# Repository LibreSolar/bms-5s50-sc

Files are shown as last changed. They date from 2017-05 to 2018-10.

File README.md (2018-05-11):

# BMS 5s (12 V)

Battery management system for up to 5 Li-ion cells based on bq76920 IC from Texas Instruments

## Boards

The Libre Solar BMS is divided into two different boards, connected via a flat cable and integrated into one housing.

### Control board (BMS 5s)

[Schematic (PDF)](power-pcb/Switch-N-Sense.pdf)

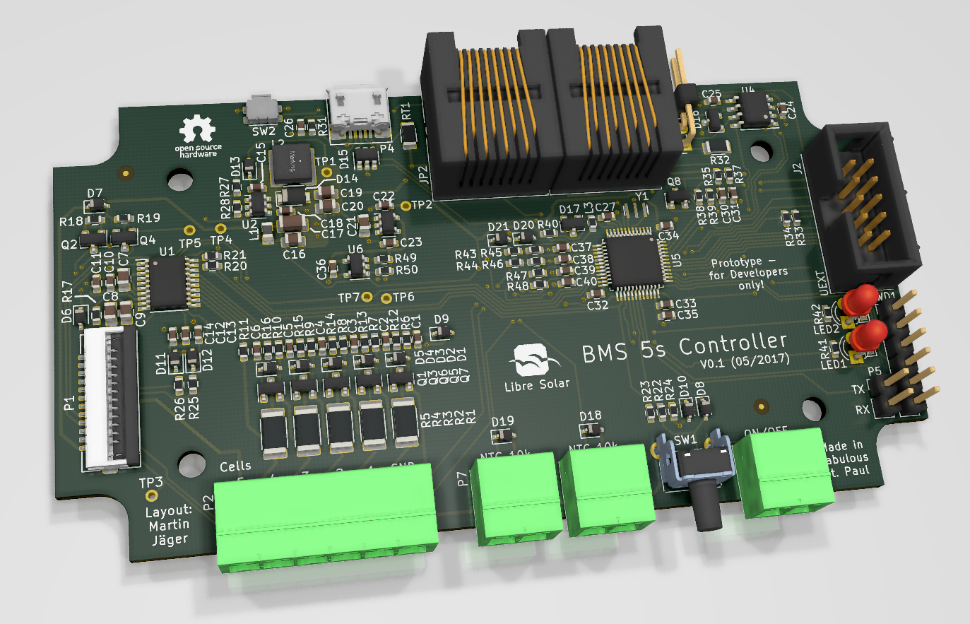
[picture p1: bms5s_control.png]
Libre Solar BMS 5s control board


### Power board (Switch-N-Sense)

[Schematic (PDF)](control-pcb/BMS-5s.pdf)

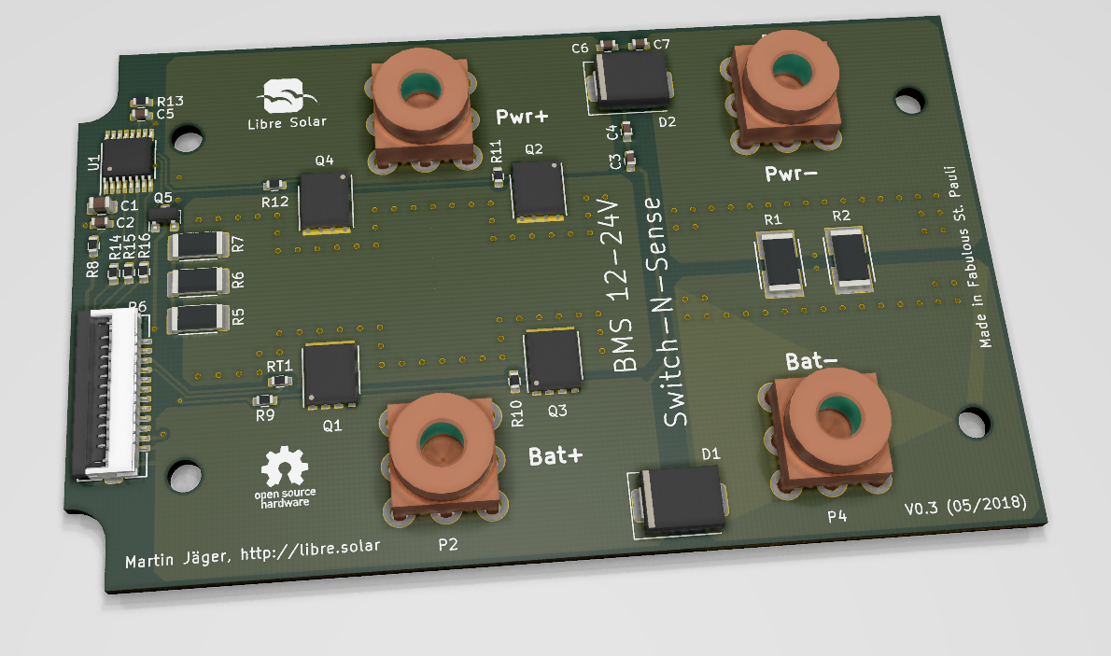
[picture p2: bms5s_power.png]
Libre Solar BMS 5s power board


## Features

- 3 to 5 Li-ion cells (e.g. LiFePO4)
- 50 A maximum current
- Balancing current approx. 150 mA
- STM32F072 ARM Cortex M0 microcontroller
- Built-in CAN communication interface and UEXT extension connector

## Housing

The BMS should fit into a Hammond Mfg 1591XXBFL housing as shown in below picture. The picture shows the BMS controller PCB with the Switch-N-Sense power PCB stacked on top of it:

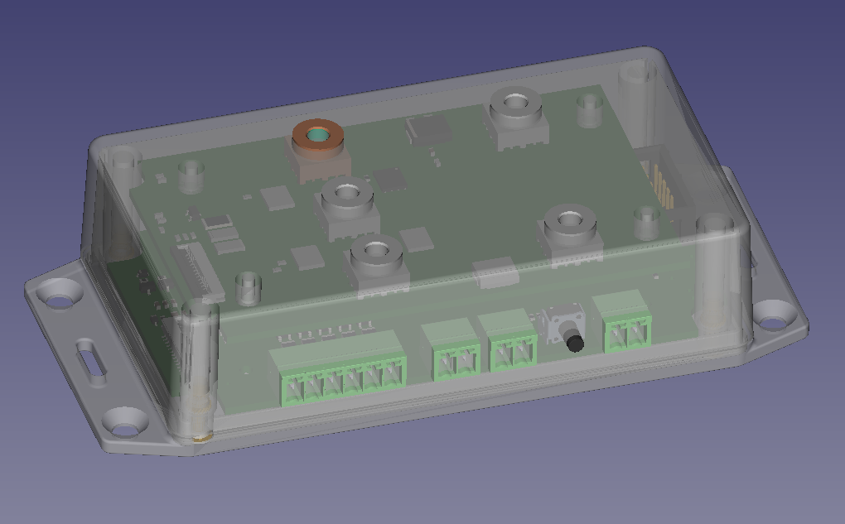
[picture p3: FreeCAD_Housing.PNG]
Libre Solar BMS 5s including housing


## History

- There is [another version of the BMS](https://github.com/LibreSolar/BMS48V)  supporting more cells and developed in Eagle CAD. This one is the first of the new BMS generation developed in KiCad. An updated version of the versions with higher number of cells might come soon.

## Important Notice

The PCBs have not been tested regarding EMC and other regulations. If you reproduce the boards, you use them at your own risk and responsibility.

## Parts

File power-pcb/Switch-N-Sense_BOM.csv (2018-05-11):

Component | Description | Part | References | Value | Footprint | Quantity Per PCB | Datasheet | PartNumber | Manufacturer | Remarks
1 | Unpolarized capacitor | C | C3 C4 C6 C7 | 100n | C_0603_1608 | 4 |  | CC0603KRX7R9BB104 | Yageo
2 | Unpolarized capacitor | C | C2 C5 | 10n | C_0603_1608 | 2 |  | CC0603KRX7R9BB103 | Yageo
3 | Unpolarized capacitor | C | C1 | 1u | C_0805_2012 | 1 |  | CC0603KRX7R8BB105 | Yageo
4 | Diode Schottky | D_Schottky | D1 D2 | SMCJ24A | D_SMC | 2 |  | SMCJ24A | Bourns
5 |  | LibreSolar_Logo | LOGO1 | LIBRE_SOLAR | LIBRESOLAR_LOGO | 1
6 | small Open Hardware Logo | Logo_Open_Hardware_Small | LOGO2 | OPEN_HARDWARE_1 | OSHW-Logo_5.7x6mm_SilkScreen | 1
7 | Generic connector, single row, 01x01, script generated (kicad-library-utils/schlib/autogen/connector/) | Conn_01x01 | P2 P3 P4 P5 | CONN_01X01 | Wuerth_WP-THRBU | 4 |  | 74650195 | Wuerth
8 |  | Conn_Switch-N-Sense_Inverted | P6 | Conn_Switch-N-Sense | Wuerth_WR-FPC_686112148922 | 1 |  | 686112148922 | Wuerth
9 | Transistor N-MOSFET (general) | Q_NMOS | Q1 Q2 Q3 Q4 | BSC014N04LS | 5X6_MOSFET | 4 |  | BSC014N04LS | Infineon
10 | Transistor P-MOSFET with substrate diode (general) | Q_PMOS_GSD | Q5 | ZXMP6A13F | SOT-23 | 1 |  | ZXMP6A13FTA | Diodes Incorporated | -60V
11 | Resistor | R | R8 R13 | 100 | R_0603_1608 | 2 |  | RC0603FR-07100RL | Yageo
12 | Resistor | R | R10 R11 | 1M | R_0603_1608 | 2 |  | RC0603FR-071ML | Yageo
13 | Resistor | R | R14 R15 R16 | 1k | R_0603_1608 | 3 |  | RC0603FR-071KL | Yageo
14 | Resistor | R | R1 R2 | 2m | R_Bourns_CRE2512 | 2 |  | CRE2512-FZ-R002E-3 | Bourns
15 | Resistor | R | R5 R6 R7 | 330 | R_2010_5025 | 3 |  | RC2010JK-07330RL | Yageo
16 | Resistor | R | R9 R12 | 4.7 | R_0603_1608 | 2 |  | RC0603FR-074R7L | Yageo
17 |  | R_NTC | RT1 | 10k | R_0603_1608 | 1 |  | NTCG163JF103FT1S | TDK
18 |  | BQ76200 | U1 | BQ76200 | TSSOP-16_4.4x5mm_P0.65mm | 1 |  | BQ76200PWR | Texas Instruments
Component Groups: | 18
Component Count: | 37
Fitted Components: | 37
Number of PCBs: | 1
Total components: | 37
Schematic Version: | 0.2
Schematic Date:
BoM Date: | 11/05/2018 13:48:19
Schematic Source: | D:\LibreSolar\2_Development\04_Hardware\BMS-5s\power-pcb\Switch-N-Sense.sch
KiCad Version: | Eeschema (5.0.0-rc2-dev-444-g2974a2c10)

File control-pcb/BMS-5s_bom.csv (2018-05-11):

Component | Description | Part | References | Value | Footprint | Quantity Per PCB | Datasheet | PartNumber | Manufacturer | Remarks | Alternative | Tolerance
1 | Unpolarized capacitor | C | C1 C2 C3 C4 C5 C6 C11 C12 C13 C14 C15 C18 C24 C25 C26 C27 C31 C32 C33 C34 C36 C37 C38 C39 C40 | 100n | C_0603_1608 | 25 |  | GRM188R71H104KA93D | Murata
2 | Unpolarized capacitor | C | C23 | 100p | C_0603_1608 | 1 |  | GRM1885C2A101JA01D | Murata
3 | Unpolarized capacitor | C | C8 C19 C20 | 10u | C_0805_2012 | 3 |  | GRM21BR61E106KA73L | Murata
4 | Unpolarized capacitor | C | C7 C9 C16 C21 | 1u | C_0603_1608 | 4 |  | GRM188R61H105KAALD | Murata | X5R
5 | Unpolarized capacitor | C | C10 C22 C30 C35 | 4.7u | C_0603_1608 | 4 |  | GRM188R61A475KE15D | Murata | 10V
6 | Unpolarized capacitor | C | C17 | 4.7u | C_1206_3216 | 1 |  | GRM31CR71H475MA12L | Murata
7 | Diode | D | D6 D8 D13 | 1N4148W-7-F | D_SOD-323 | 3 |  | 1N4148W-7-F | Diodes Inc.
8 | Diode zener | D_Zener | D9 D10 D11 D12 D18 D19 D20 D21 | 3.3V | D_SOD-323 | 8 |  | MM3Z3V3T1G | ON Semiconductor
9 | Diode zener | D_Zener | D1 D2 D3 D4 D5 D7 | 5.6V | D_SOD-323 | 6 |  | MM3Z5V6T1G | ON Semiconductor |  | BZX384-C5V6
10 |  | LM4040 | D17 | LM4040CYM3-2.5 | SOT-23 | 1 |  | LM4040DYM3-2.5-TR | Microchip
11 |  | NUP2105L | D16 | NUP2105L | SOT-23 | 1 |  | NUP2105LT1G | ON Semiconductor
12 | Diode Schottky | D_Schottky | D14 | SS16FP | D_PowerDI-123 | 1 |  | SS16FP | Diodes Inc. |  | DFLS160-7
13 |  | USBLC6-2SC6 | D15 | USBLC6-2SC6 | SOT-23-6 | 1 |  | USBLC6-2SC6 | STMicroelectronics |  | WE-TVS 82400102
14 |  | UEXT | J2 | UEXT | Box_Header_2x05x2.54mm_Straight | 1 |  | 61201021621 | Würth
15 | Jumper normally close | Jumper_NC_Small | JP1 | Jumper_NC_Small | Pin_Header_Angled_2x01_Pitch2.54mm | 1
16 |  | RJ45_NS | JP2 JP3 | RJ45_NS | RJ45_8P8C | 2 |  | 54602-908LF | Amphenol FCI
17 | Inductor | L | L2 | 22uH | L_WE-TPC-4818 | 1 |  | SRR4028-220Y | Bourns |  | WE-TPC-4818 744042220
18 | Inductor | L | L1 | 4.7uH | L_0805 | 1 |  | LQM21PN4R7NGRD | Murata
19 | Inductor | L | L3 | L | R_0603_1608 | 1 |  | BLM18AG601SN1D | Murata
20 |  | LED | LED1 LED2 | LED | LED_D3.0mm | 2
21 | Libre Solar Logo | LIBRE_SOLAR | LOGO2 | LIBRE_SOLAR | LIBRESOLAR_LOGO | 1
22 | Open Hardware Logo | OPEN_HARDWARE_1 | LOGO1 | OPEN_HARDWARE_1 | OSHW-Logo_5.7x6mm_SilkScreen | 1
23 | Connector, single row, 01x02, pin header | CONN_01X02 | P5 | CONN_01X02 | Pin_Header_Straight_1x02_Pitch2.54mm | 1
24 | Connector, single row, 01x02, pin header | CONN_01X02 | P6 P7 | CONN_01X02 | Phoenix_Contact_PTSM_0.5_2-HH-2,5-THR-R16 | 2
25 | Connector, single row, 01x06, pin header | CONN_01X06 | P2 | CONN_01X06 | Phoenix_Contact_MC_1,5_6-G-3,81 | 1 |  | 1803316 | Phoenix Contact | MC 1,5/ 6-G-3,81
26 |  | Conn_Switch-N-Sense | P1 | Conn_Switch-N-Sense | Wuerth_WR-FPC_687112149022 | 1 |  | 687112149022 | Würth
27 | Connector, single row, 01x02, pin header | CONN_01X02 | P3 | ON/OFF | Phoenix_Contact_PTSM_0.5_2-HH-2,5-THR-R16 | 1 |  |  | Phoenix Contact
28 |  | USB_OTG | P4 | USB_Micro-B | USB_Micro-B_10103594-0001LF | 1 |  | 10103594-0001LF | FCI
29 | Transistor N-MOSFETwith substrate diode (general) | Q_NMOS_GSD | Q4 Q8 Q9 | 2N7002 | SOT-23 | 3 |  | 2N7002,215 | Nexperia
30 | Transistor N-MOSFETwith substrate diode (general) | Q_NMOS_GSD | Q2 | BSS84 | SOT-23 | 1 |  | BSS84 | Fairchild Semiconductor
31 | Transistor N-MOSFETwith substrate diode (general) | Q_NMOS_GSD | Q1 Q3 Q5 Q6 Q7 | DMN2004K | SOT-23 | 5 |  | DMN2004K-7 | Diodes Incorporated
32 | Resistor | R | R17 | 100 | R_0603_1608 | 1 |  | RC0603FR-07100RL | Yageo
33 | Resistor | R | R18 R19 R24 R31 R43 R44 | 100k | R_0603_1608 | 6 |  | RC0603FR-07100KL | Yageo
34 | Resistor | R | R12 R13 R14 R15 R16 R22 R28 R40 R45 R46 R47 R48 | 10k | R_0603_1608 | 12 |  | RC0603FR-0710KL | Yageo
35 | Resistor | R | R32 | 120 | R_1206_3216 | 1 |  | RC1206FR-07120RL | Yageo
36 | Resistor | R | R21 R35 R37 | 1M | R_0603_1608 | 3 |  | RC0603FR-071ML | Yageo
37 | Resistor | R | R6 R7 R8 R9 R10 R11 R20 R25 R26 | 1k | R_0603_1608 | 9 |  | RC0603FR-071KL | Yageo
38 | Resistor | R | R33 R34 R38 R49 R50 | 2.2k | R_0603_1608 | 5 |  | RC0603FR-072K2L | Yageo
39 | Resistor | R | R1 R2 R3 R4 R5 | 33 | R_2010_5025 | 5 |  | RC2010JK-0733RL | Yageo
40 | Resistor | R | R41 R42 | 330 | R_0603_1608 | 2 |  | RC0603FR-07330RL | Yageo
41 | Resistor | R | R23 | 5.6K | R_0603_1608 | 1 |  | RC0603FR-075K6L | Yageo
42 | Resistor | R | R27 R39 | 52.3k | R_0603_1608 | 2 |  | RC0603FR-0752K3L | Yageo
43 |  | R_PTC | RT1 | 200mA | R_0805_2012 | 1 |  | 0805L020 | Littelfuse
44 | Button | SW_PUSH | SW1 | SW_PUSH | SW_Tactile_SKHH_Angled | 1 |  | 431256083716 | Würth
45 | Button | SW_PUSH | SW2 | SW_PUSH | SW_SPST_EVQP7A | 1 |  | 434121050816 | Würth
46 |  | ST_Nucleo_SWD | SWD1 | ST_Nucleo_SWD | Pin_Header_Straight_1x05_Pitch2.54mm | 1
47 | Microchip 24AA01 1K I2C EEPROM | 24AA01 | U6 | 24AA01 | SOT-23-5 | 1 |  | 24AA01 | Microchip
48 | 300mA low dropout linear regulator, shutdown pin, 1.5V fixed positive output, SOT-23-5 package | AP2210-3.3 | U3 | AP2210-3.3 | SOT-23-5 | 1 | http://www.diodes.com/_files/datasheets/AP131.pdf | AP2210K-3.3TRG1 | Diodes Inc. |  | MIC5225
49 |  | BQ76920 | U1 | BQ76920 | TSSOP-20_4.4x6.5mm_Pitch0.65mm | 1 |  | BQ7692003PWR | Texas Instruments
50 | High-Voltage Input Integrated Switch Step-Down Regulator, 50V, 500mA | MCP16331-CH | U2 | MCP16331-CH | SOT-23-6 | 1 | http://ww1.microchip.com/downloads/en/DeviceDoc/20005308C.pdf | MCP16331T-E/CH | Microchip
51 |  | STM32F072CB | U5 | STM32F072CB | LQFP-48_7x7mm_Pitch0.5mm | 1 |  | STM32F072CBT6 | STMicroelectronics
52 | TJA1042T/3, High-Speed CAN Transceiver, separate VIO, standby mode, SOIC-8 | TJA1042T/3 | U4 | TJA1042T/3 | SOIC-8_3.9x4.9mm_Pitch1.27mm | 1 | http://www.nxp.com/documents/data_sheet/TJA1042.pdf | TJA1042T/3/1J | NXP
53 | Two pin crystal | Resonator | Y1 | 8kHz | Resonator_Murata_CSTCE | 1 |  | CSTCE8M00G15C99-R0 | Murata |  |  | 0.1%
Component Groups: | 53
Component Count: | 144
Fitted Components: | 144
Number of PCBs: | 1
Total components: | 144
Schematic Version: | 0.1b
Schematic Date: | 3 dec 2016
BoM Date: | 22/05/2017 16:05:45
Schematic Source: | D:\LibreSolar\2_Development\04_Hardware\BMS-5s\BMS-5s.sch
KiCad Version: | Eeschema (2017-05-10 revision 747583606)-makepkg

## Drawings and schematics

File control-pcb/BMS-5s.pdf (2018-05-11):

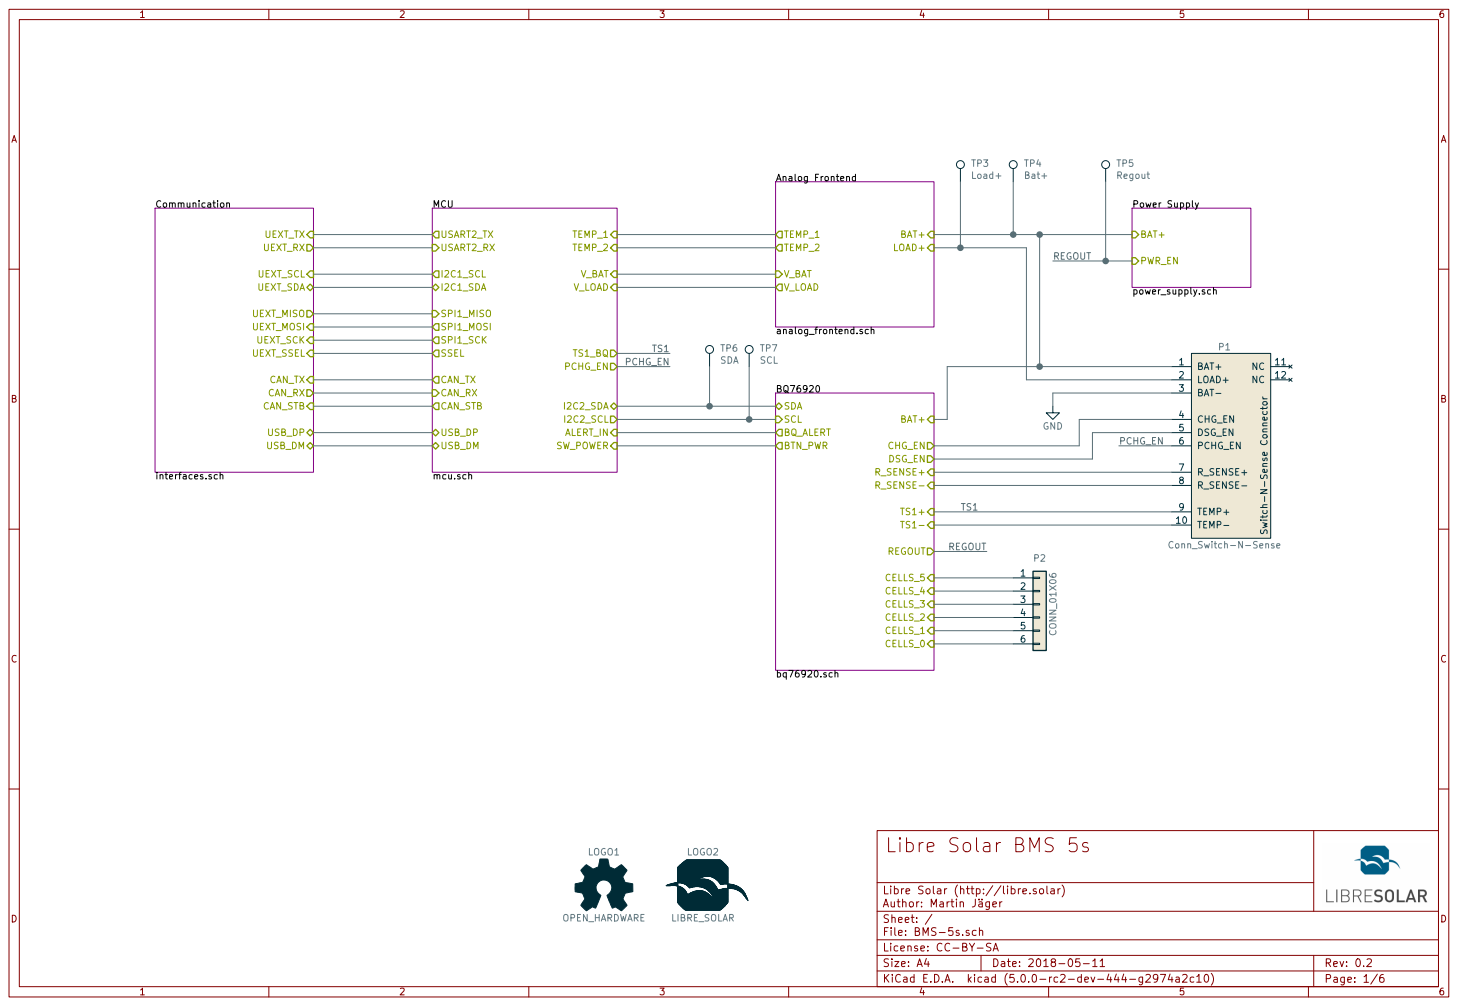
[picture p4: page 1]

File: BMS-5s.sch Sheet: / Libre Solar (http://libre.solar) License: CC-BY-SA
Author: Martin Jäger

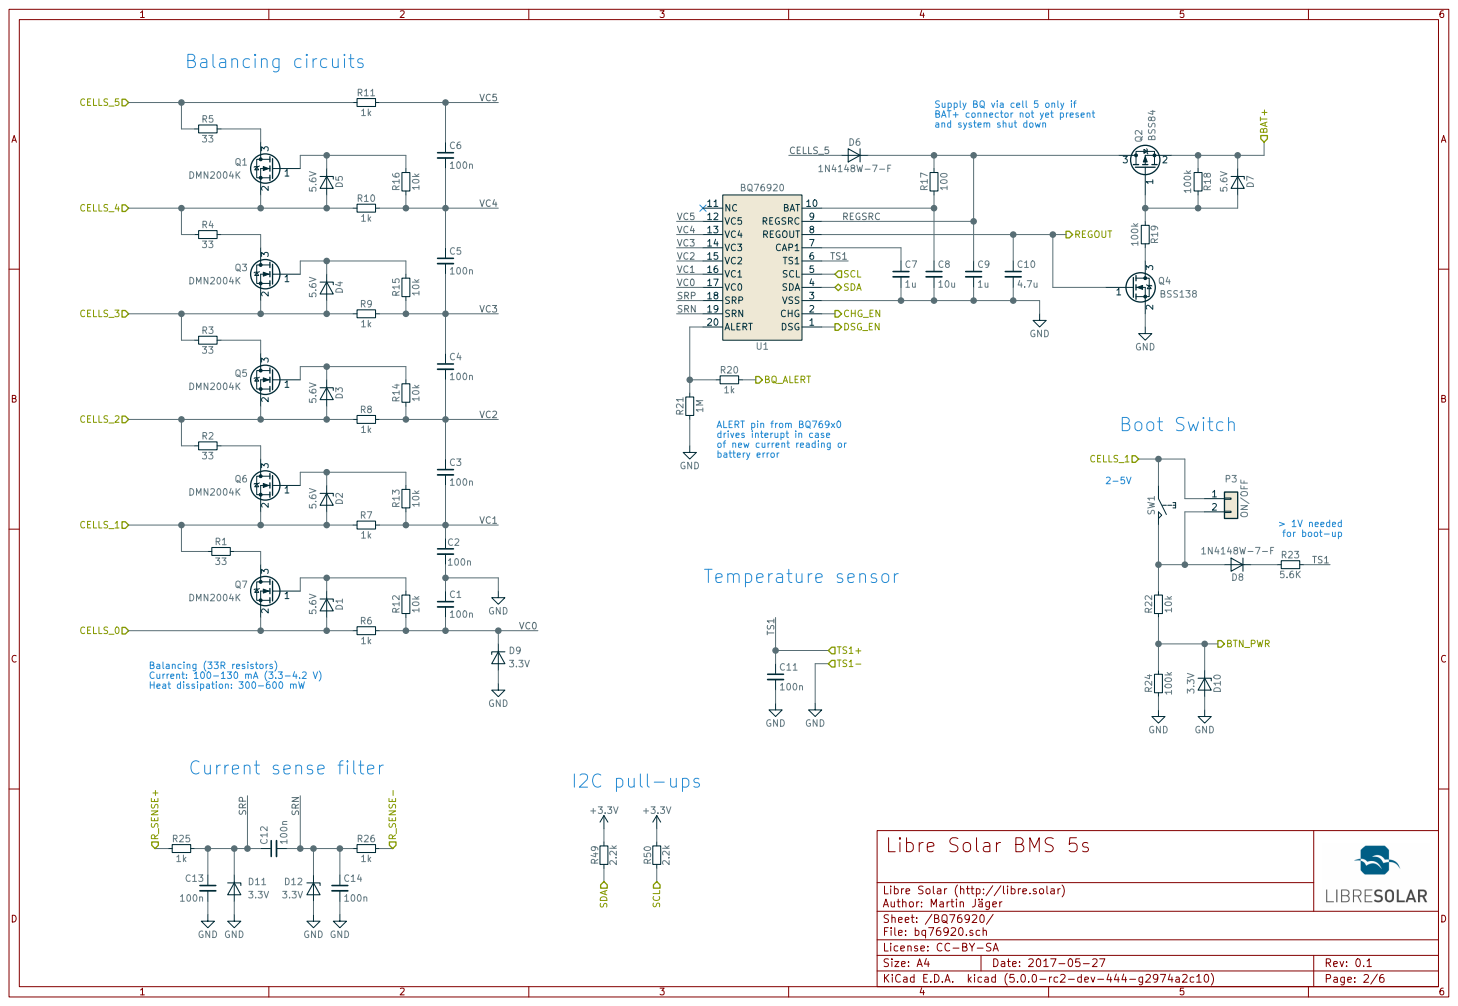
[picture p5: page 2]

REGOUT Supply BQ via cell 5 only if
BAT+ connector not yet present

2 3 Q7 DMN2004K GND GND GND GND GND GND

ALERT pin from BQ769x0
drives interupt in case
of new current reading or

Libre Solar (http://libre.solar) License: CC-BY-SA

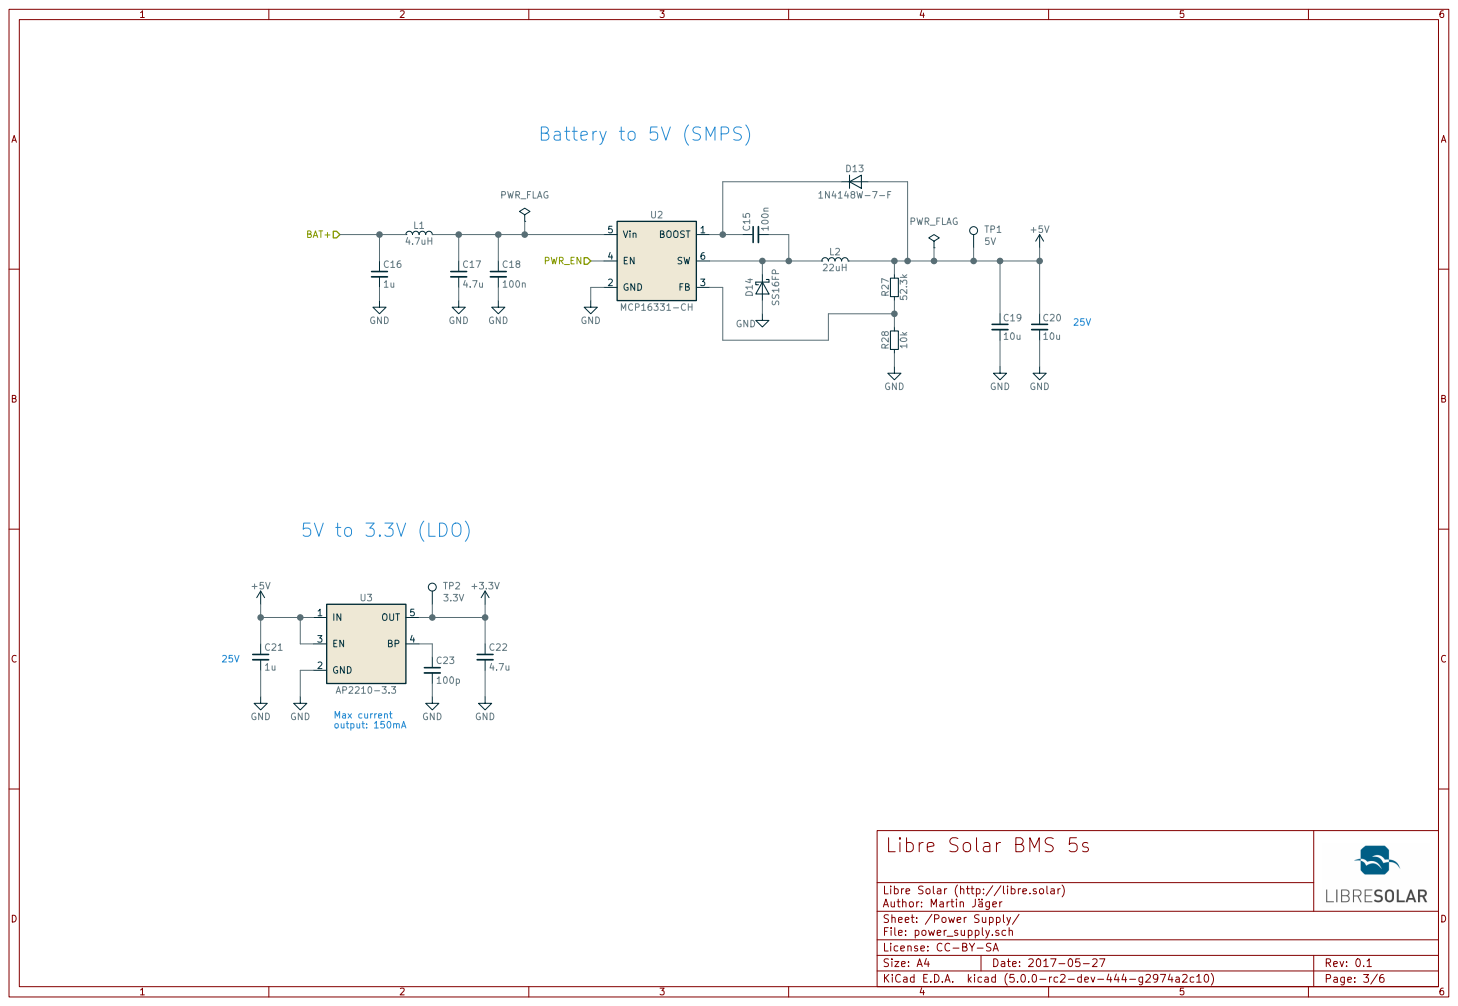
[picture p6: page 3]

Libre Solar (http://libre.solar) License: CC-BY-SA

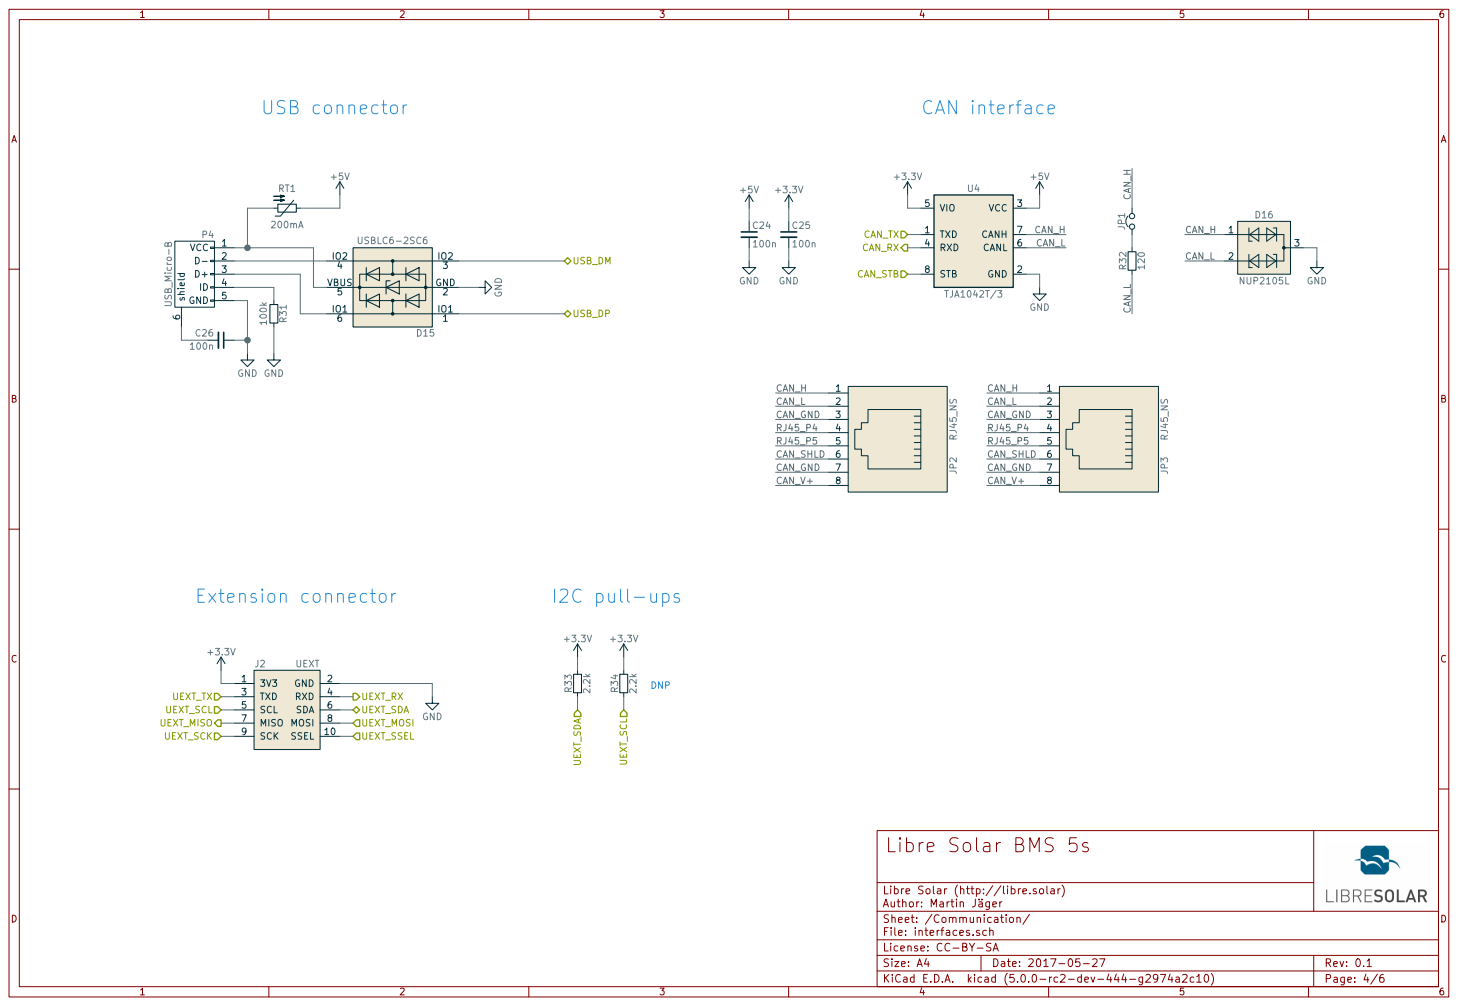
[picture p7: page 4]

File: interfaces.sch Sheet: /Communication/ Libre Solar (http://libre.solar) License: CC-BY-SA
Author: Martin Jäger

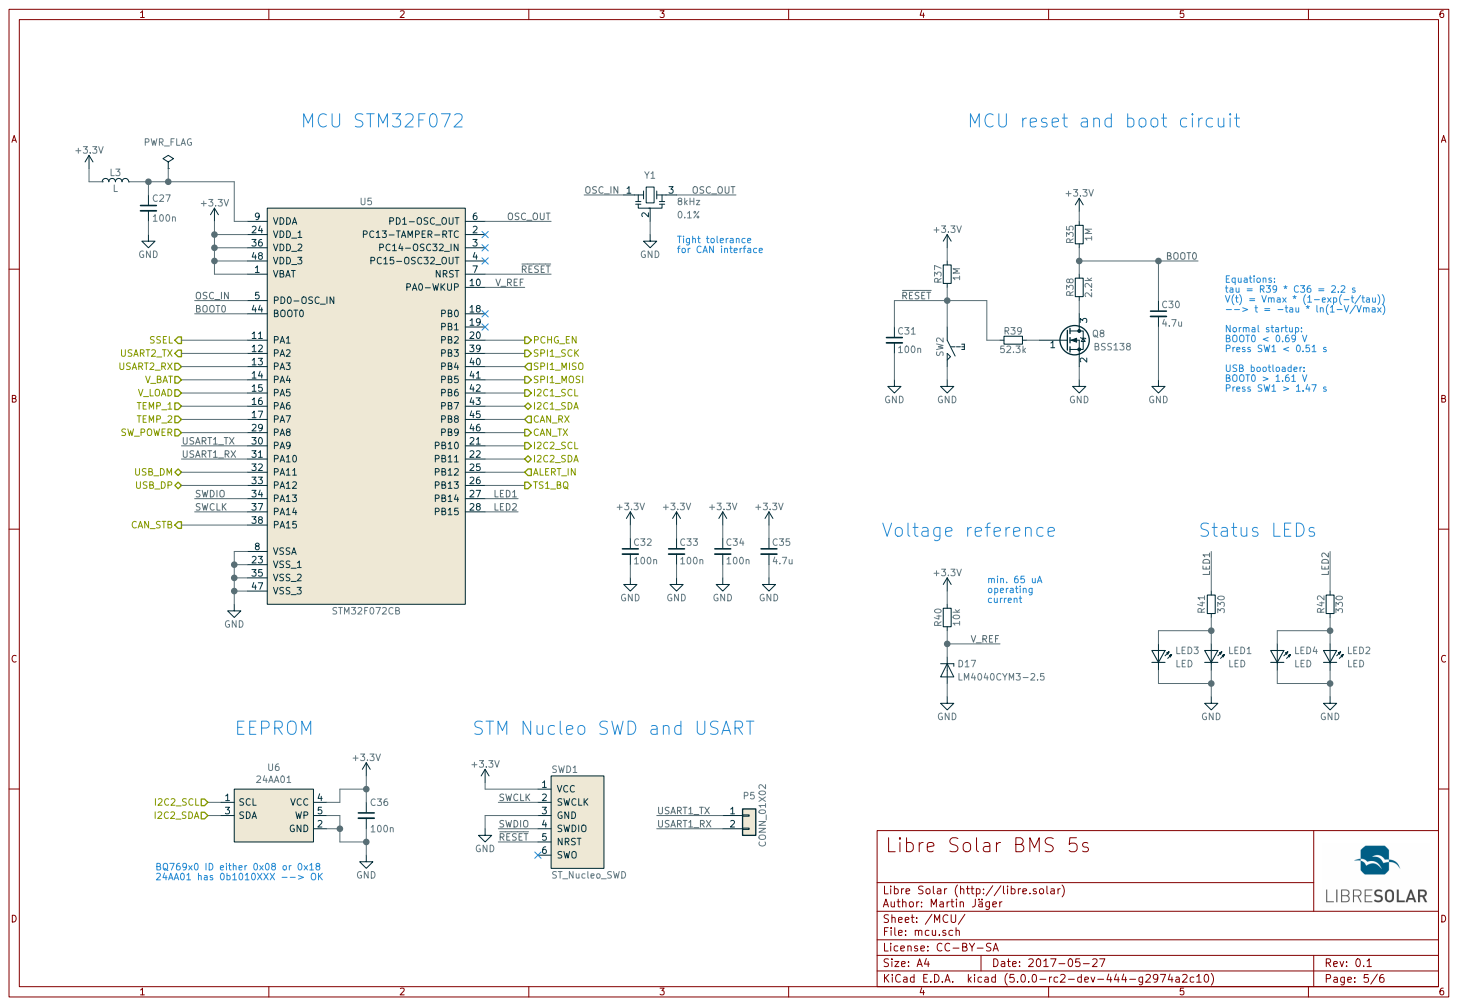
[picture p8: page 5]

MCU reset and boot circuit

for CAN interface BQ769x0 ID either 0x08 or 0x18

Equations:
tau = R39 * C36 = 2.2 s V(t) = Vmax * (1-exp(-t/tau))
--> t = -tau * ln(1-V/Vmax)
Normal startup: BOOT0 < 0.69 V
Press SW1 < 0.51 s USB bootloader: BOOT0 > 1.61 V

STM Nucleo SWD and USART

File: mcu.sch Sheet: /MCU/ Libre Solar (http://libre.solar) License: CC-BY-SA

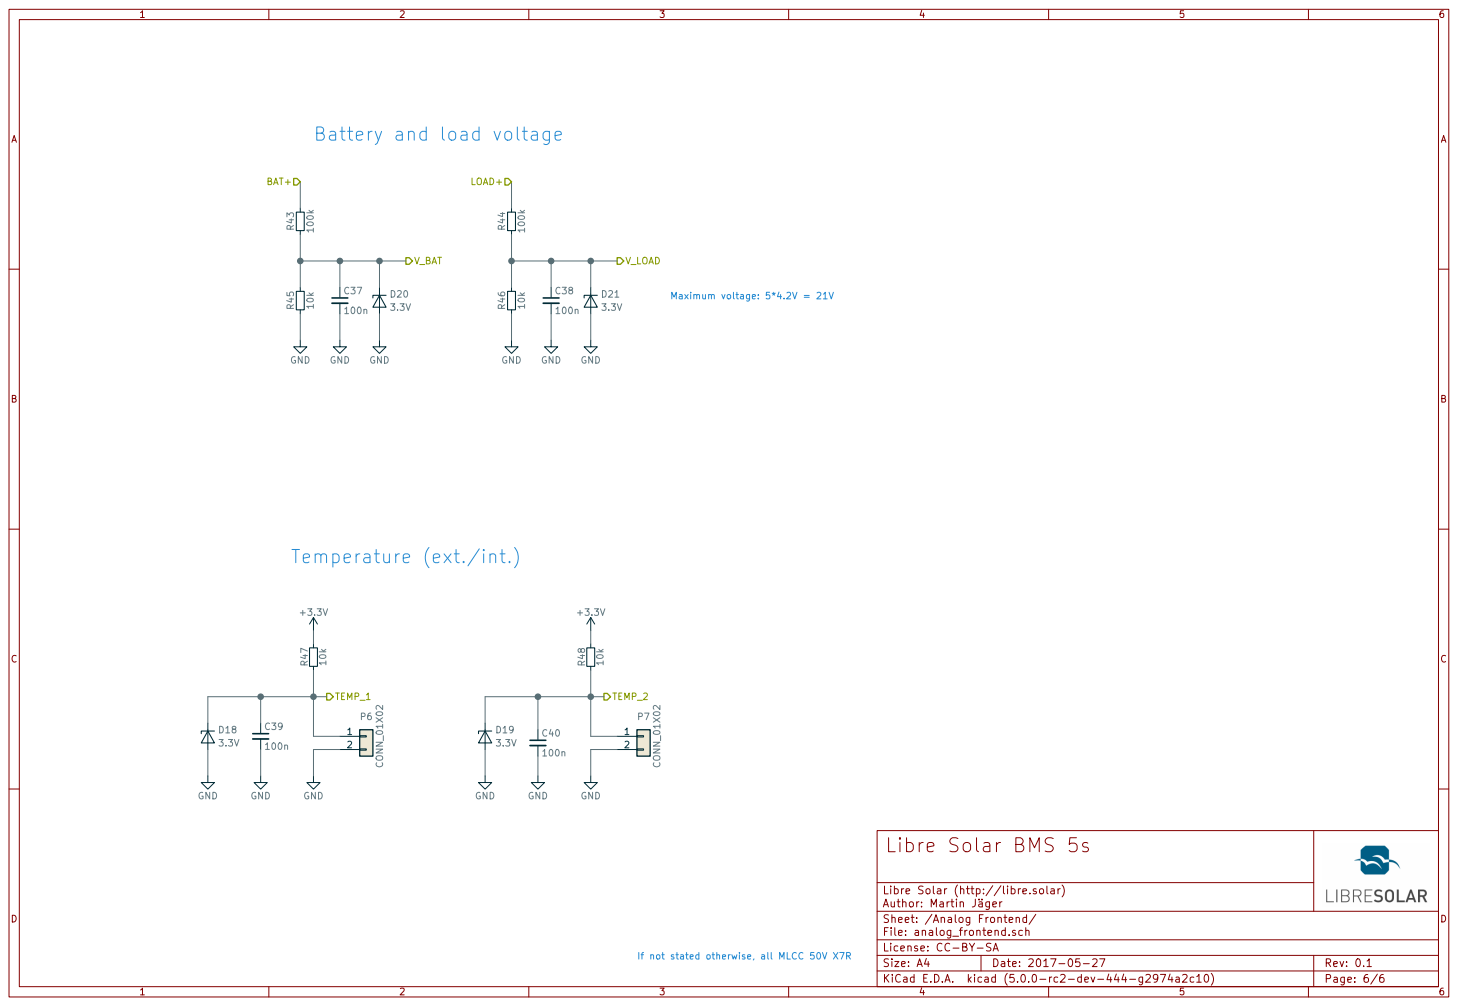
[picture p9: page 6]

100n Battery and load voltage

Libre Solar (http://libre.solar) License: CC-BY-SA

If not stated otherwise, all MLCC 50V X7R

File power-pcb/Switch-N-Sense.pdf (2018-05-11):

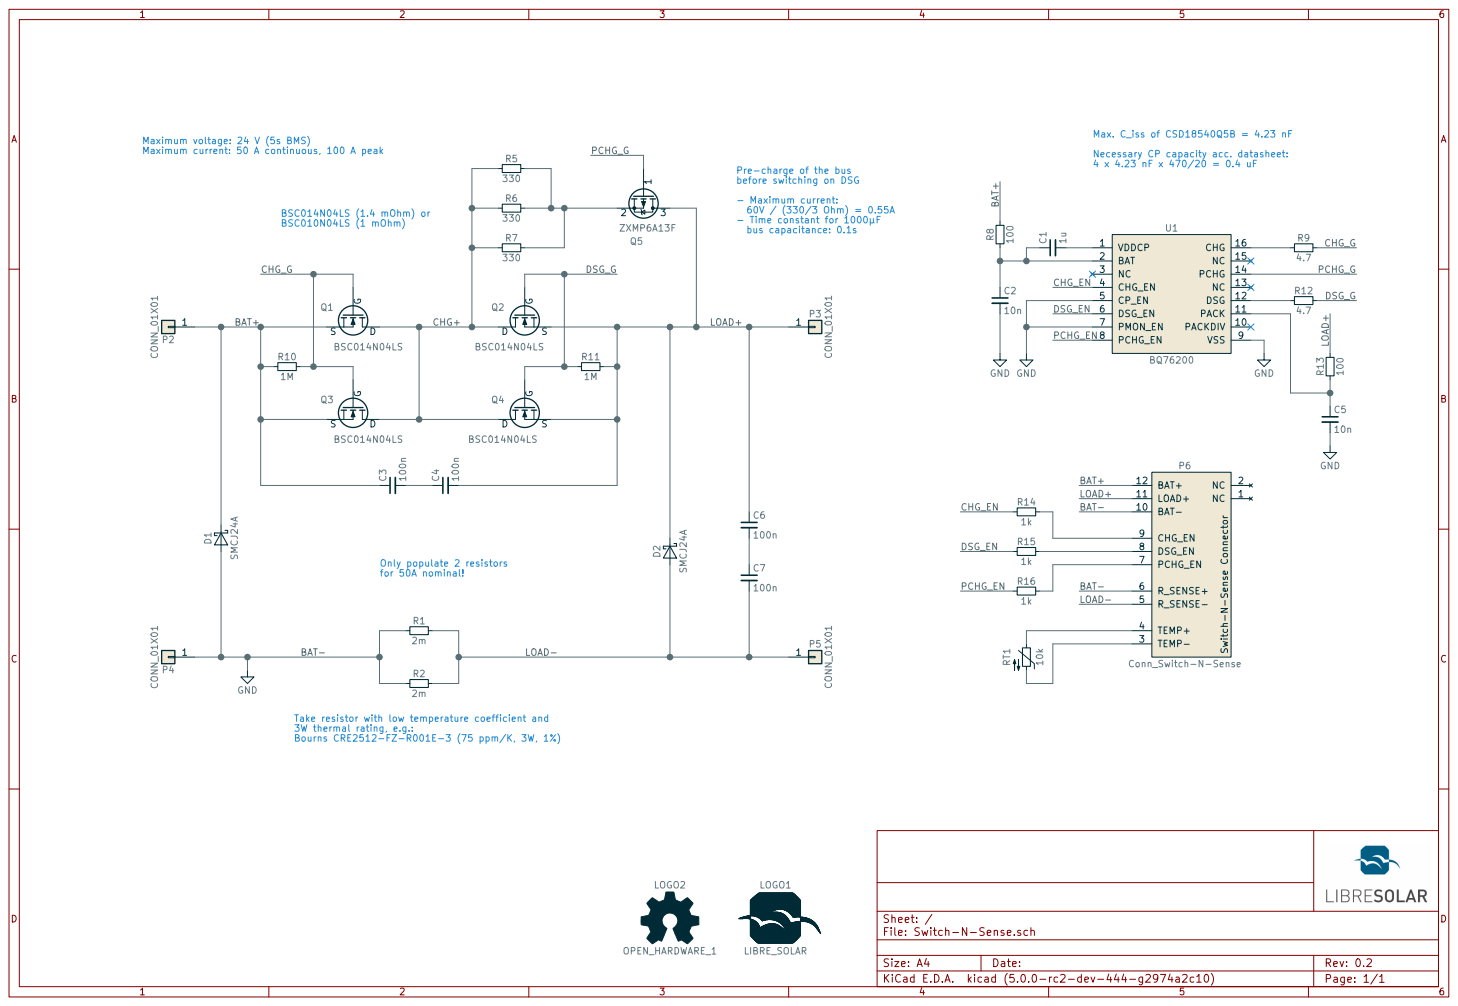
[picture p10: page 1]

for 50A nominal! Maximum voltage: 24 V (5s BMS)

Pre-charge of the bus
before switching on DSG
- Maximum current:
60V / (330/3 Ohm) = 0.55A
- Time constant for 1000µF
bus capacitance: 0.1s

LOAD+ BAT- LOAD- BAT- Only populate 2 resistors

Take resistor with low temperature coefficient and
3W thermal rating, e.g.:

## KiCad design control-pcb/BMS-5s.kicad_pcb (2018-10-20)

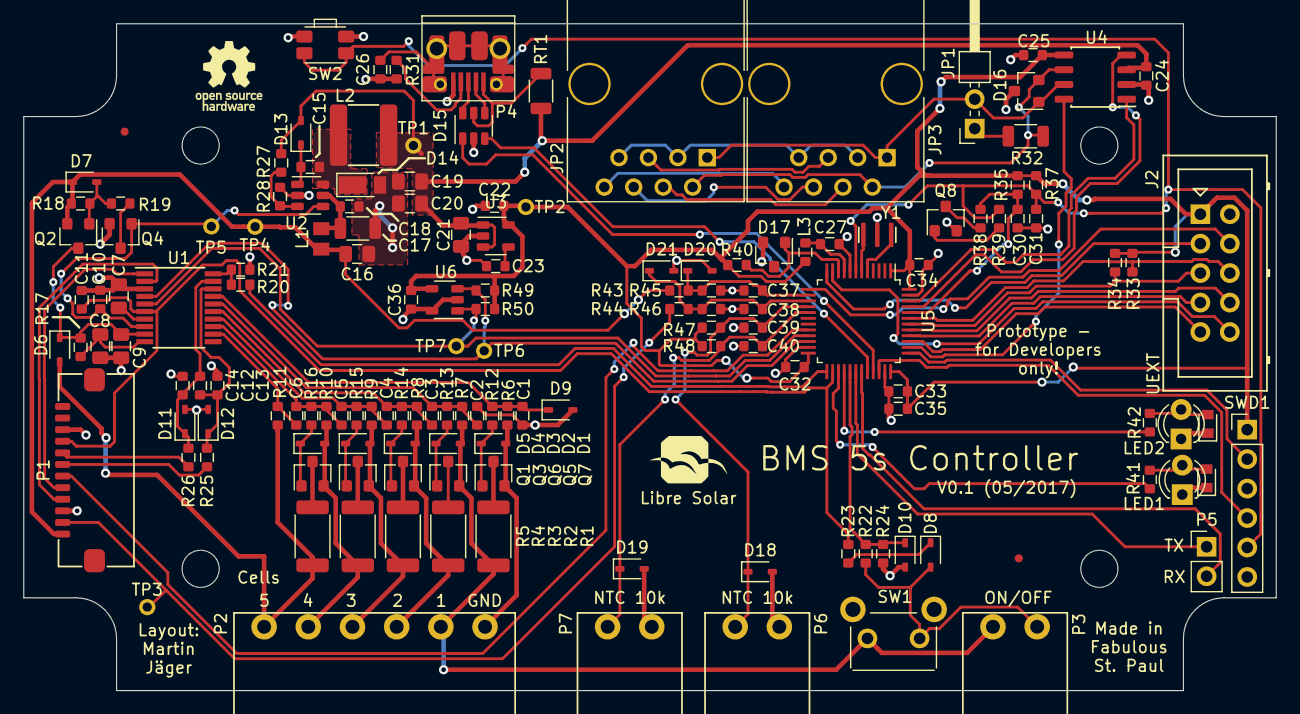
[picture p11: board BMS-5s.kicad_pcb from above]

Board: 2 copper layers, 108.0 x 57.5 mm, 152 parts (0 on the bottom side), 99 nets.

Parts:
C1, C2, C3, C4, C5, C6, C11, C12, C13, C14, C15, C18, C24, C25, C26, C27, C31, C32, C33, C34, C36, C37, C38, C39, C40: 100n; C_0603_1608
C7, C9, C16, C21: 1u; C_0805_2012
C8, C19, C20: 10u; C_0805_2012
C10, C22, C30, C35: 4.7u; C_0603_1608
C17: 4.7u; C_1206_3216
C23: 100p; C_0603_1608
D1, D2, D3, D4, D5, D7: 5.6V; D_SOD-323
D6, D8, D13: 1N4148WS-7-F; D_SOD-323
D9, D10, D11, D12, D18, D19, D20, D21: 3.3V; D_SOD-323
D14: SS16FP; D_PowerDI-123
D15: USBLC6-2SC6; SOT-23-6
D16: NUP2105L; SOT-23
D17: LM4040CYM3-2.5; SOT-23
J2: UEXT; Box_Header_2x05x2.54mm_Straight
JP1: Jumper_NC_Small; PinHeader_2x01_P2.54mm_Horizontal
JP2, JP3: RJ45_NS; RJ45_8P8C
L1: 4.7uH; L_0805_2012Metric
L2: 22uH; L_WE-TPC-4818
L3: L; R_0603_1608
LED1, LED2: LED; LED_D3.0mm
LED3, LED4: LED; LED_0603_1608Metric
LOGO1: OPEN_HARDWARE; OSHW-Logo_5.7x6mm_SilkScreen
LOGO2: LIBRE_SOLAR; LIBRESOLAR_LOGO
P1: Conn_Switch-N-Sense; Wuerth_WR-FPC_686112148922
P2: CONN_01X06; Phoenix_Contact_MC_1,5_6-G-3,81
P3: ON/OFF; Phoenix_Contact_MC_1,5_2-G-3,81
P4: USB_Micro-B; USB_Micro-B_10103594-0001LF
P5: CONN_01X02; PinHeader_1x02_P2.54mm_Vertical
P6, P7: CONN_01X02; Phoenix_Contact_MC_1,5_2-G-3,81
Q1, Q3, Q5, Q6, Q7: DMN2004K; SOT-23
Q2: BSS84; SOT-23
Q4, Q8: BSS138; SOT-23
R1, R2, R3, R4, R5: 33; R_2010_5025
R6, R7, R8, R9, R10, R11, R20, R25, R26: 1k; R_0603_1608
R12, R13, R14, R15, R16, R22, R28, R40, R45, R46, R47, R48: 10k; R_0603_1608
R17: 100; R_0603_1608
R18, R19, R24, R31, R43, R44: 100k; R_0603_1608
R21, R35, R37: 1M; R_0603_1608
R23: 5.6K; R_0603_1608
R27, R39: 52.3k; R_0603_1608
R32: 120; R_1206_3216
R33, R34, R38, R49, R50: 2.2k; R_0603_1608
R41, R42: 330; R_0603_1608
RT1: 200mA; R_1206_3216
SW1: SW_PUSH; SW_Tactile_SKHH_Angled
SW2: SW_PUSH; SW_SPST_EVQP7A
SWD1: ST_Nucleo_SWD; PinHeader_1x06_P2.54mm_Vertical
TP1: 5V; TestPoint_0.8mm_hole
TP2: 3.3V; TestPoint_0.8mm_hole
TP3: Load+; TestPoint_0.8mm_hole
TP4: Bat+; TestPoint_0.8mm_hole
TP5: Regout; TestPoint_0.8mm_hole
TP6: SDA; TestPoint_0.8mm_hole
TP7: SCL; TestPoint_0.8mm_hole
U1: BQ76920; TSSOP-20_4.4x6.5mm_P0.65mm
U2: MCP16331-CH; SOT-23-6
U3: AP2210-3.3; SOT-23-5
U4: TJA1042T/3; SOIC-8_3.9x4.9mm_Pitch1.27mm
U5: STM32F072CB; LQFP-48_7x7mm_P0.5mm
U6: 24AA01; SOT-23-5
Y1: 8kHz; Resonator_Murata_CSTCE_G

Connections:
+3V3: C22.1, C25.1, C32.1, C33.1, C34.1, C35.1, C36.1, J2.1, L3.1, R33.2, R34.2, R35.2, R37.2, R40.2, R47.1, R48.1, R49.2, R50.2, SWD1.1, TP2.1, U3.5, U4.5, U5.1, U5.24, U5.36, U5.48, U6.4
+5V: C19.1, C20.1, C21.1, C24.1, D13.2, L2.2, R27.1, RT1.1, TP1.1, U3.1, U3.3, U4.3
/Analog Frontend/BAT+: C16.1, D7.1, L1.1, P1.1, Q2.2, R18.2, R43.1, TP4.1
/Analog Frontend/LOAD+: P1.2, R44.1, TP3.1
/Analog Frontend/TEMP_1: C39.1, D18.1, P6.1, R47.2, U5.16
/Analog Frontend/TEMP_2: C40.1, D19.1, P7.1, R48.2, U5.17
/Analog Frontend/V_BAT: C37.1, D20.1, R43.2, R45.1, U5.14
/Analog Frontend/V_LOAD: C38.1, D21.1, R44.2, R46.1, U5.15
/BQ76920/BTN_PWR: D10.1, R22.2, R24.1, U5.29
/BQ76920/CELLS_0: D1.2, P2.6, Q7.2, R6.2
/BQ76920/CELLS_1: D2.2, P2.5, P3.1, Q6.2, R1.2, R7.2, SW1.1
/BQ76920/CELLS_2: D3.2, P2.4, Q5.2, R2.2, R8.2
/BQ76920/CELLS_3: D4.2, P2.3, Q3.2, R3.2, R9.2
/BQ76920/CELLS_4: D5.2, P2.2, Q1.2, R4.2, R10.2
/BQ76920/CELLS_5: D6.2, P2.1, R5.2, R11.2
/BQ76920/CHG_EN: P1.4, U1.2
/BQ76920/DSG_EN: P1.5, U1.1
/BQ76920/REGSRC: C9.1, D6.1, Q2.3, R17.1, U1.9
/BQ76920/R_SENSE+: P1.7, R25.2
/BQ76920/R_SENSE-: P1.8, R26.1
/BQ76920/SRN: C12.2, C14.1, D12.1, R26.2, U1.19
/BQ76920/SRP: C12.1, C13.1, D11.1, R25.1, U1.18
/BQ76920/VC0: C1.2, D9.1, R6.1, R12.2, U1.17
/BQ76920/VC1: C2.1, C3.2, R7.1, R13.2, U1.16
/BQ76920/VC2: C3.1, C4.2, R8.1, R14.2, U1.15
/BQ76920/VC3: C4.1, C5.2, R9.1, R15.2, U1.14
/BQ76920/VC4: C5.1, C6.2, R10.1, R16.2, U1.13
/BQ76920/VC5: C6.1, R11.1, U1.12
/Communication/CAN_GND: JP2.3, JP2.7, JP3.3, JP3.7
/Communication/CAN_H: D16.1, JP1.2, JP2.1, JP3.1, U4.7
/Communication/CAN_L: D16.2, JP2.2, JP3.2, R32.2, U4.6
/Communication/CAN_RX: U4.4, U5.45
/Communication/CAN_SHLD: JP2.6, JP3.6
/Communication/CAN_STB: U4.8, U5.38
/Communication/CAN_TX: U4.1, U5.46
/Communication/CAN_V+: JP2.8, JP3.8
/Communication/RJ45_P4: JP2.4, JP3.4
/Communication/RJ45_P5: JP2.5, JP3.5
/Communication/UEXT_RX: J2.4, U5.13
/Communication/UEXT_TX: J2.3, U5.12
/Communication/USB_DM: D15.3, U5.32
/Communication/USB_DP: D15.1, U5.33
/MCU/ALERT_IN: R20.1, U5.25
/MCU/BOOT0: C30.1, R35.1, R38.2, U5.44
/MCU/I2C1_SCL: J2.5, R34.1, U5.42
/MCU/I2C1_SDA: J2.6, R33.1, U5.43
/MCU/I2C2_SCL: R50.1, TP7.1, U1.5, U5.21, U6.1
/MCU/I2C2_SDA: R49.1, TP6.1, U1.4, U5.22, U6.3
/MCU/LED1: R41.2, U5.27
/MCU/LED2: R42.2, U5.28
/MCU/OSC_IN: U5.5, Y1.1
/MCU/OSC_OUT: U5.6, Y1.3
/MCU/SPI1_MISO: J2.7, U5.40
/MCU/SPI1_MOSI: J2.8, U5.41
/MCU/SPI1_SCK: J2.9, U5.39
/MCU/SSEL: J2.10, U5.11
/MCU/SWCLK: SWD1.2, U5.37
/MCU/SWDIO: SWD1.4, U5.34
/MCU/USART1_RX: P5.2, U5.31
/MCU/USART1_TX: P5.1, U5.30
/MCU/V_REF: D17.1, R40.1, U5.10
/MCU/~RESET: C31.1, R37.1, R39.1, SW2.1, SWD1.5, U5.7
/PCHG_EN: P1.6, U5.20
/REGOUT: C10.1, Q4.1, TP5.1, U1.8, U2.4
/TS1: C11.1, P1.9, R23.2, U1.6, U5.26
GND: C1.1, C2.2, C7.2, C8.2, C9.2, C10.2, C11.2, C13.2, C14.2, C16.2, C17.2, C18.2, C19.2, C20.2, C21.2, C22.2, C23.2, C24.2, C25.2, C26.1, C27.2, C30.2, C31.2, C32.2, C33.2, C34.2, C35.2, C36.2, C37.2, C38.2, C39.2, C40.2, D9.2, D10.2, D11.2, D12.2, D14.2, D15.2, D16.3, D17.2, D18.2, D19.2, D20.2, D21.2, J2.2, LED1.1, LED2.1, LED3.1, LED4.1, P1.3, P1.10, P4.5, P6.2, P7.2, Q4.2, Q8.2, R21.2, R24.2, R28.2, R31.2, R45.2, R46.2, SW2.2, SWD1.3, U1.3, U2.2, U3.2, U4.2, U5.8, U5.23, U5.35, U5.47, U6.2, U6.5, Y1.2
unnamed: C7.1, U1.7
unnamed: C8.1, R17.2, U1.10
unnamed: C15.1, D13.1, U2.1
unnamed: C15.2, D14.1, L2.1, U2.6
unnamed: C17.1, C18.1, L1.2, U2.5
unnamed: C23.1, U3.4
unnamed: C26.2, P4.6
unnamed: C27.1, L3.2, U5.9
unnamed: D1.1, Q7.1, R12.1
unnamed: D2.1, Q6.1, R13.1
unnamed: D3.1, Q5.1, R14.1
unnamed: D4.1, Q3.1, R15.1
unnamed: D5.1, Q1.1, R16.1
unnamed: D7.2, Q2.1, R18.1, R19.2
unnamed: D8.1, R23.1
unnamed: D8.2, P3.2, R22.1, SW1.2
unnamed: D15.4, P4.2
unnamed: D15.5, P4.1, RT1.2
unnamed: D15.6, P4.3
unnamed: JP1.1, R32.1
unnamed: LED1.2, LED3.2, R41.1
unnamed: LED2.2, LED4.2, R42.1
unnamed: P4.4, R31.1
unnamed: Q1.3, R5.1
unnamed: Q3.3, R4.1
unnamed: Q4.3, R19.1
unnamed: Q5.3, R3.1
unnamed: Q6.3, R2.1
unnamed: Q7.3, R1.1
unnamed: Q8.1, R39.2
unnamed: Q8.3, R38.1
unnamed: R20.2, R21.1, U1.20
unnamed: R27.2, R28.1, U2.3

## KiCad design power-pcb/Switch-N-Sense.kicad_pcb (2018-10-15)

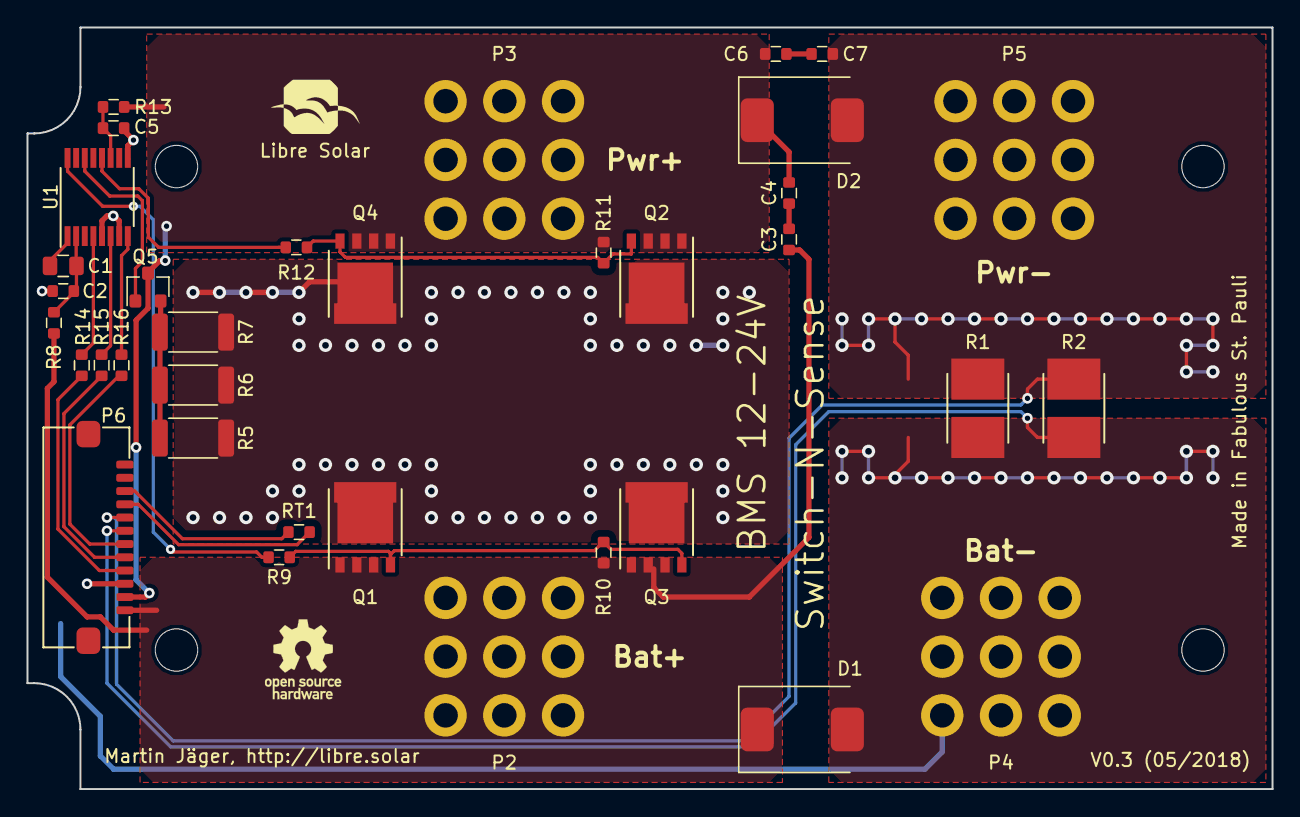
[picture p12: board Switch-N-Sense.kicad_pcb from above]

Board: 2 copper layers, 94.0 x 57.5 mm, 37 parts (0 on the bottom side), 24 nets.

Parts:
C1: 1u; C_0805_2012
C2, C5: 10n; C_0603_1608
C3, C4, C6, C7: 100n; C_0603_1608
D1, D2: SMCJ24A; D_SMC
LOGO1: LIBRE_SOLAR; LIBRESOLAR_LOGO
LOGO2: OPEN_HARDWARE_1; OSHW-Logo_5.7x6mm_SilkScreen
P2, P3, P4, P5: CONN_01X01; Wuerth_WP-THRBU
P6: Conn_Switch-N-Sense; Wuerth_WR-FPC_686112148922
Q1, Q2, Q3, Q4: BSC014N04LS; 5X6_MOSFET
Q5: ZXMP6A13F; SOT-23
R1, R2: 2m; R_Bourns_CRE2512
R5, R6, R7: 330; R_2010_5025
R8, R13: 100; R_0603_1608
R9, R12: 4.7; R_0603_1608
R10, R11: 1M; R_0603_1608
R14, R15, R16: 1k; R_0603_1608
RT1: 10k; R_0603_1608
U1: BQ76200; TSSOP-16_4.4x5mm_P0.65mm

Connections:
/BAT+: C3.1, D1.1, P2.1, P6.12, Q1.S, Q3.S, R8.2, R10.2
/CHG+: Q1.D, Q2.D, Q3.D, Q4.D, R5.2, R6.2, R7.2
/CHG_EN: R14.2, U1.4
/CHG_G: Q1.G, Q3.G, R9.1, R10.1
/DSG_EN: R15.2, U1.6
/DSG_G: Q2.G, Q4.G, R11.2, R12.1
/LOAD+: C4.2, C6.1, D2.1, P3.1, P6.11, Q2.S, Q4.S, Q5.3, R11.1, R13.2
/LOAD-: C7.2, D2.2, P5.1, P6.5, R1.1, R2.1
/PCHG_EN: R16.2, U1.8
/PCHG_G: Q5.1, U1.14
GND: C2.2, C5.2, D1.2, P4.1, P6.6, P6.10, R1.2, R2.2, U1.5, U1.7, U1.9
unnamed: C1.1, C2.1, R8.1, U1.2
unnamed: C1.2, U1.1
unnamed: C3.2, C4.1
unnamed: C5.1, R13.1, U1.11
unnamed: C6.2, C7.1
unnamed: P6.3, RT1.2
unnamed: P6.4, RT1.1
unnamed: P6.7, R16.1
unnamed: P6.8, R15.1
unnamed: P6.9, R14.1
unnamed: Q5.2, R5.1, R6.1, R7.1
unnamed: R9.2, U1.16
unnamed: R12.2, U1.12

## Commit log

2017-06-01 Small fixes for final gerber export (DRU check passed)
    [BMS-5s.kicad_pcb, BMS-5s.sch, analog_frontend.sch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]
2017-06-01 Switch-N-Sense (power PCB) added
    [BMS-5s-B.Cu.gbl, BMS-5s-B.Mask.gbs, BMS-5s-B.SilkS.gbo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]
2017-06-14 Issues #1, #2 and #4 fixed
    [BMS-5s.kicad_pcb, BMS-5s.sch, Switch-N-Sense.kicad_pcb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]
2017-10-22 Issue #6 fixed
    [BMS-5s.kicad_pcb, Switch-N-Sense.kicad_pcb, Switch-N-Sense.sch]
2017-10-22 Small changes in power PCB
    [Switch-N-Sense.sch]
2018-05-11 Update to KiCAD 5 and minor changes in part selection
    [BMS-5s.kicad_pcb, BMS-5s.sch, BMS-5s_bom.csv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]
2018-05-11 Gerber removed and BOM files added.
    [BMS-5s-B.Cu.gbl, BMS-5s-B.Mask.gbs, BMS-5s-B.SilkS.gbo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]
2018-05-11 Direct link to schematic added.
    [BMS-5s.FCStd, BMS-5s.kicad_pcb]
2018-07-03 Step file of control PCB added.
2018-10-15 DRC errors corrected
    [BMS-5s.kicad_pcb, Switch-N-Sense.kicad_pcb]
2018-10-20 Diode part number corrected, closing issue #9
    [BMS-5s.kicad_pcb, bq76920.sch, power_supply.sch]
